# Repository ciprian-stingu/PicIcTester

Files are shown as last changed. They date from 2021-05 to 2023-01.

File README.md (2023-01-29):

# PicIcTester
IC Tester using PICs

I made this project because I have a lot of 7400-series digital logic integrated circuits acquired from flea market and I wanted to verify them.  
The tester is using a **PIC18F452-I/P** to perform the tests and a **PIC16F628A** to handle the display, keypad and relays.

## Main features

* Search IC by name
* Create, run and store and load custom tests directly on tester
* Run tests created on a connected computer
* IC identification
* Can test logic circuits with pinout count between 2 and 28 pins
* IC in narrow or normal packaging
* Default testing will use relays to activate the IC power pins
* IC identification will use low power, so the tester can't damage the IC
* Keypad operation
* Computer connection
* Single sided PCB, so you can made it at home

## Compiled code
Here are the hex files which contain the compiled code for [PIC18F452-I/P aka Tester](binaries/Tester.production.hex) and [PIC16F628A aka Interface](binaries/Interface.production.hex).

## Database
The tester uses a modified database which I found on [Smart-IC-Tester](https://github.com/akshaybaweja/Smart-IC-Tester).  
In order to speed up the search on database I created an index at the start of it. I shrinked it by using the Unix line endings and by merging identical tests. Also some teste were fixed or updated.  
The program which handle the database indexing is in [DbCreate](DbCreate) folder.  
The ready for use database file is [here](Database/database.txt.bin)

## Database storage
To store the database I used an **24LC256** (256Kb I2C compatible 2-wire Serial EEPROM) but you can use an eeprom up to 64KiB in size.

## Display
I'm using a **Nokia 3510i LCD** with a modified code from [Interfacing Nokia 3510i and 5110 LCD with PIC Microcontroller](http://www.toughdev.com/content/2011/03/interfacing-nokia-3510i-and-5110-lcd-with-pic-microcontroller/)

## Font
I'm using a modified and stripped down version of **TINYTYPE** from [8x8 Pixel ROM Font Editor](https://www.min.at/prinz/o/software/pixelfont/)

## Hardware
All the files which you need in order to create the PCBs are in the [hardware](hardware) folder.

## Case
The files for 3D printing a case are available in [FreeCAD](FreeCAD) folder

## Menu &amp; navigation

Navigate in main menu using *UP* and *DOWN* keys, pressing the *OK* key will activate the selected option  

* Search &amp; Test
    * Enter Search IC screen using the *OK* key
        * When in search box you can enter the device name using the keypad (keys *0* through *9*)
        * To select a device use the *DONW* key
            * At this step you can cancel and return to main screen using the *LEFT* key
            * Enter the test screen using the *OK* key
                * Navigate between buttons using *UP* and *DOWN* keys
                * Start testing by selecting *START* button and then press *OK* key
                    * Test result is displayed
                        * Pressing any key will close this screen and return to test screen
                * Return to main menu using *CLOSE* button
* PC Test
    * Enter PC Test screen using the *OK* key
        * To cancel the PC test press any key
        * After receiving the test data from PC, the tester will enter the PC test screen
            * Here you have 3 options: *START*, *SAVE*, *CLOSE*
            * Choosing *START* will run the test received from PC
            * You can save the test in *PIC18F452* EEPROM for later use using the *SAVE* button
            * Return to main menu using *CLOSE* button
* Custom Test
    * Enter Custom test screen using the *OK* key
        * If a previous test was saved, here you have the option to load it back from eeprom
            * Choosing *NO* will proceed to create a new custom test
            * Choosing *YES* will load the test from eeprom and will advance to test screen
        * If no previous test exist or you choose to ignore the existing custom test, it will display the Custom test name screen
            * Enter a test name using the keys *0* through *9*
            * You can remove the last character entered using the *LEFT* key
            * When ready, use the *DOWN* key to select the *OK* button and using the *OK* key advance to Test Pins screen
                * Here you can specify the number of pins for the subject IC, only even numbers and up to 28 pins
                * You can remove the last char using *LEFT* key
                * When ready, use the *DOWN* key to select the *OK* button and using the *OK* key advance to Test cases screen
                    * Here you can specify one test case at a time
                    * You can enter the test case using the keys from *0* through *7*
                        * 0 key -> displays 0 -> INPUT PIN LOW
                        * 1 key -> displays 1 -> INPUT PIN HIGH
                        * 2 key -> displays L -> OUTPUT PIN LOW
                        * 3 key -> displays H -> OUTPUT PIN HIGH
                        * 4 key -> displays G -> PIN as POWER GROUND
                        * 5 key -> displays V -> PIN as POWER VCC
                        * 6 key -> displays X -> DON'T USE the PIN
                        * 7 key -> displays C -> USE the PIN as CLOCK
                    * You can remove the last char using *LEFT* key
                    * You need to enter the same number of chars as the previously specified IC pins. If you have more chars than the number of pins, the tester will ignore excess data.
                    * When ready, use the *DOWN* key to select the *NEXT* button to confirm the current test case
                    * After entering and confirming at least one test case you can use the *DONE* button to advance to Start Test screen
                        * Here you have the same options as on PC Test screen
* Identify IC
    * Enter Identify IC screen using the *OK* key
        * Here you need to specify the number of pins which IC has, using keys *0* through *9*
        * You can remove the last char using *LEFT* key
        * You can return to main menu using *DOWN* key, selecting the *CLOSE* button and using the *OK* key
        * When ready use the *DOWN* key, select *START* button and pressing the *OK* key to start the identifying process
            * The identification process is not using the relays, so in some cases the IC will be not found because, probably, it require more power than the 20mA available from PIC I/O ports
            * Also, if the IC is defective, the identification process will fail
            * When identification process is finished, the result found or not found is displayed. 
                * From this screen, pressing any key will return to main menu
* About
    * Enter About screen using the *OK* key
        * Information about tester will be displayed
        * Pressing any key will return to main menu

## PC communication protocol
The PC can be connected to the tester using an commonly available **USB to UART converter** with a baud rate of 115200/8-N-1 and using unix line endings
The tester will not respond if the line sent was processed correctly, but will send back errors if the data was not ok.
The following protocol is used in order to transmit a test case, one line at a time

```
TEST BEGIN
TEST NAME The Test Name (up to 14 chars)
TEST PINS Number of pins (up to 28 pins and even number)
TEST CASE The test case data (following chars are allowed: 0,1,L,H,G,V,X,C and has to match the number of IC pins)
... more test cases... up to 48 test cases
TEST END

```
You can abort the test transmision using `ABORT`  
After receiving the `END` keyword the tester will respond `Test data complete` and will be ready to run the test

Example
```
TEST BEGIN
TEST NAME 74244
TEST PINS 20
TEST CASE 10H0H0H0HG0H0H0H0H1V
TEST CASE 11H1H1H1HG1H1H1H1H1V
TEST CASE 00L0L0L0LG0L0L0L0L0V
TEST CASE 01H1H1H1HG1H1H1H1H0V
TEST CASE 00H0H0H0HG1L1L1L1L0V
TEST CASE 01L1L1L1LG0H0H0H0H0V
TEST CASE 01H0H1H0HG1L0H1L0H1V
TEST CASE 10H1L0H1LG0H1H0H1H0V
TEST END
```

## Limitations in current implementation
* Only one test case can be saved in tester eeprom memory
* Only 240 bytes of eeprom data is available for storage of a test case
* The database can be up to 64KiB in size
* The communication between PIC18F452-I/P and PIC16F628A is visible on UART
* You can have only 32767 tests in database
* You can have only 48 test cases in each test
* Maximum message length on UART is 79 characters
* 7 relays are used to implement common power configuration for ICs

## Supported ICs
4000, 4001, 4002, 4009, 4049, 4010, 4050, 4011, 4012, 4013, 4015, 4016, 4066, 4017, 4018, 4019, 4020, 4022, 4023, 4024, 4025, 4027, 4028, 4029, 4030, 4031, 4040, 4041, 4042, 4043, 4044, 4048, 4049, 4051, 4053, 4066, 4068, 4069, 40106, 4070, 4071, 4072, 4073, 4075, 4076, 4077, 4078, 4081, 4082, 4093, 4094, 4098, 40106, 40160, 40162, 40161, 40163, 40174, 40175, 40192, 40193, 4501, 4503, 4506, 4510, 4511, 4512, 4518, 4519, 4520, 4529, 4532, 4543, 4572, 7400, 7403, 7437, 7438, 7401, 7402, 7428, 7404, 7405, 7406, 7414, 7416, 7407, 7417, 7408, 7409, 7410, 7412, 7411, 7413, 7418, 7420, 7440, 74140, 7415, 7421, 7422, 7425, 7426, 7427, 7430, 7432, 7442, 7446, 7447, 7450, 7451, 7452, 7455, 7458, 7460, 7461, 7462, 7465, 7472, 7474, 7475, 7485, 7486, 74107, 74109, 74112, 74113, 74123, 74125, 74126, 74132, 74133, 74136, 74137, 74138, 74139, 74145, 74147, 74148, 74151, 74153, 74157, 74158, 74160, 74161, 74162, 74163, 74164, 74165, 74166, 74173, 74174, 74175, 74182, 74190, 74191, 74192, 74193, 74194, 74195, 74237, 74242, 74243, 74244, 74251, 74253, 74257, 74258, 74259, 74260, 74266, 74280, 74283, 74292, 74293, 74294, 74298, 74365, 74366, 74367, 74368, 74373, 74374, 74375, 74386, 74390, 74393, 74589, 74595, 74597

## Assembled tester
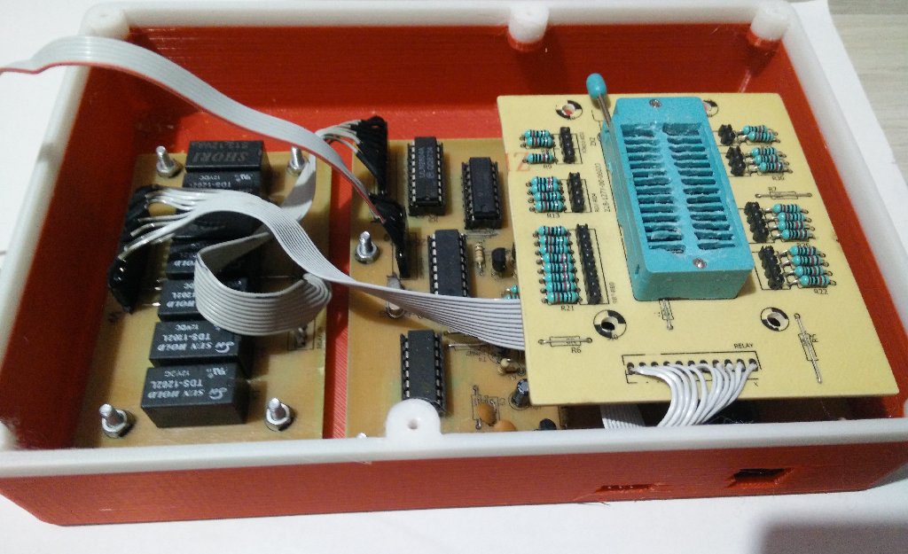
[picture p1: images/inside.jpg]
Inside
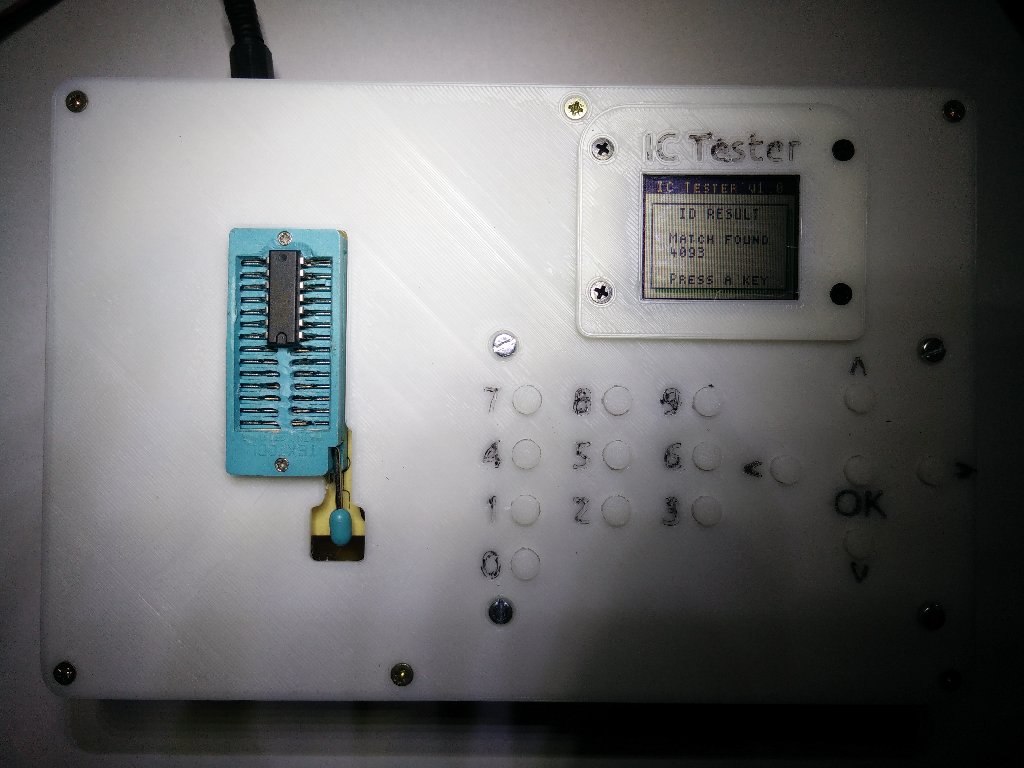
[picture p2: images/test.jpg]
Test
 

## Menu images
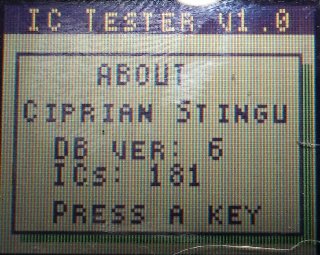
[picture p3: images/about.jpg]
About
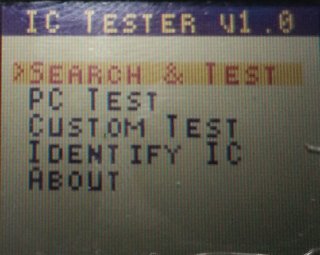
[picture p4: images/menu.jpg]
Menu
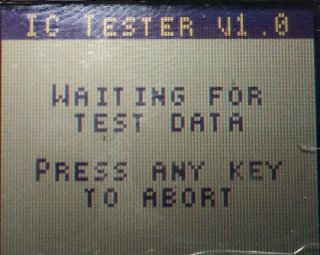
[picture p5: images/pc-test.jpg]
Pc test
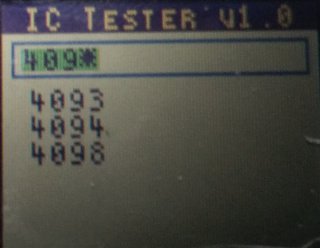
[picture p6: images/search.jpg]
Search
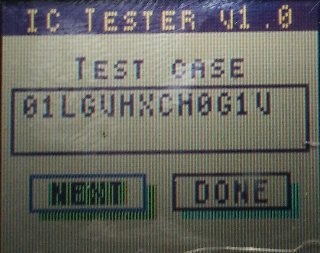
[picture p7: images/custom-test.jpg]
Custom test
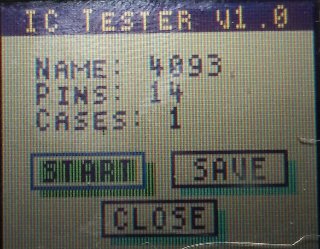
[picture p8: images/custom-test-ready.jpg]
Custom test ready
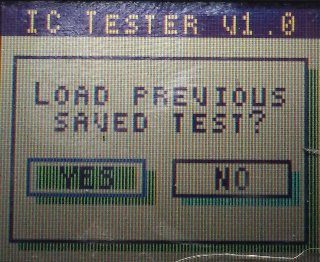
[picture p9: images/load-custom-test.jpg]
Load custom test
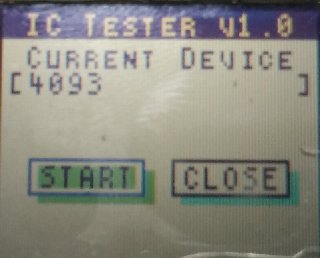
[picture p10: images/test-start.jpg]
Test start
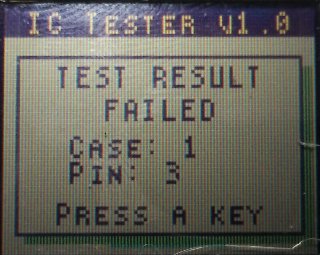
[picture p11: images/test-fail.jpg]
Test fail
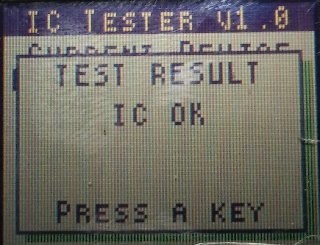
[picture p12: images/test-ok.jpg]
Test ok


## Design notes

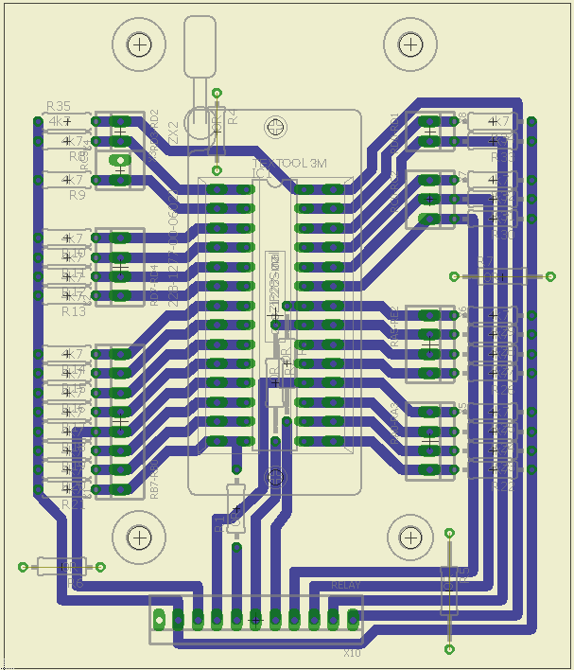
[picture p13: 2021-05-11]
hardware/socket-pcb.png

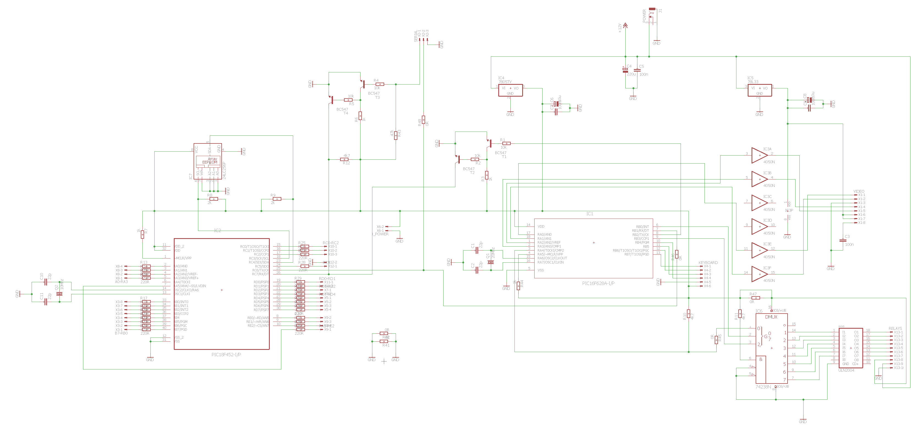
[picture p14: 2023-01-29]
hardware/main-schematic.png

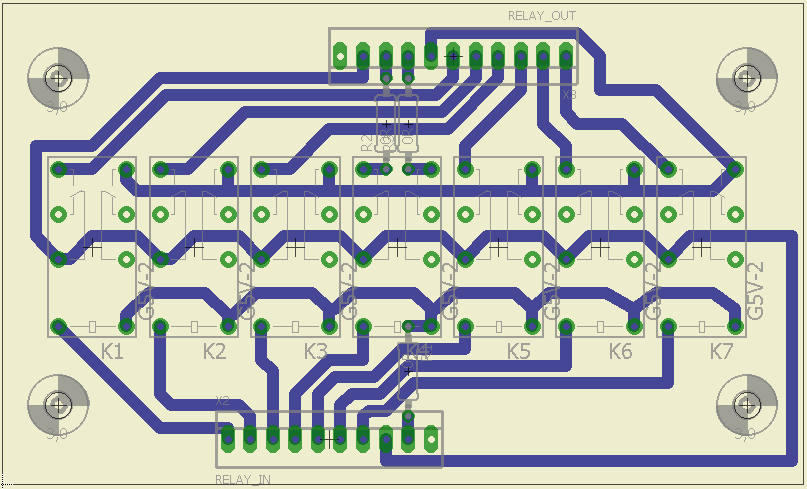
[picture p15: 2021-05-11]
hardware/relay-pcb.png

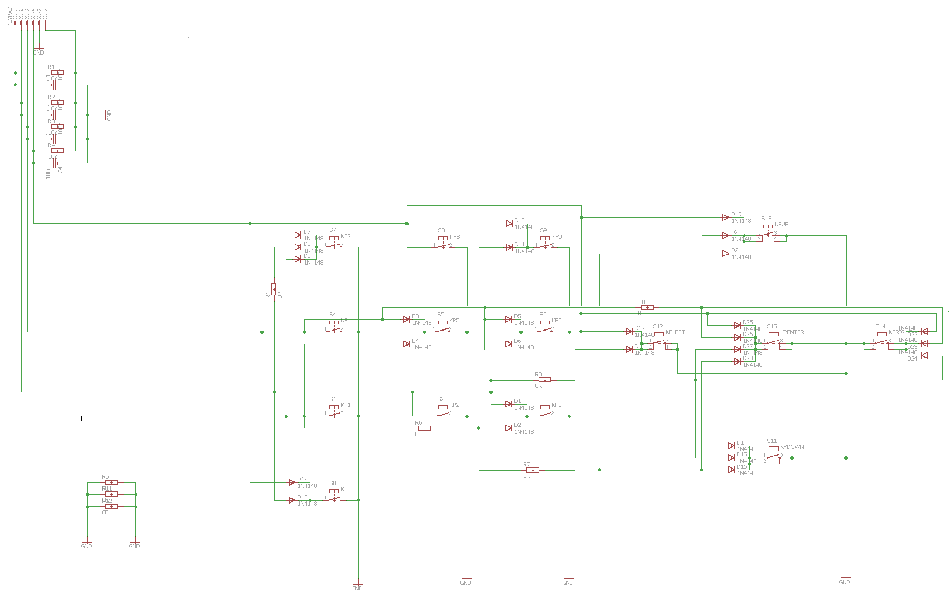
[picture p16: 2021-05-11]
hardware/keypad-schematic.png

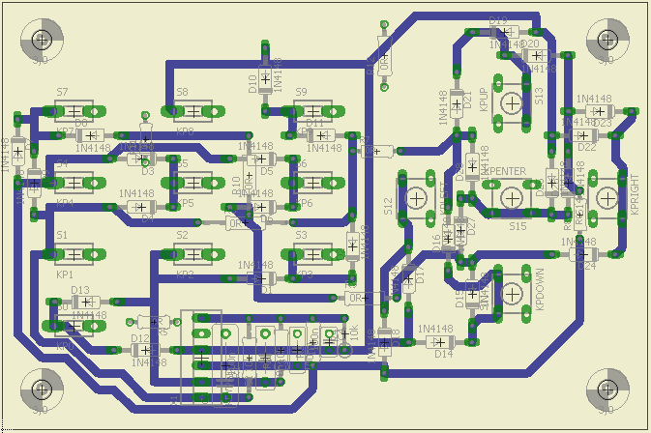
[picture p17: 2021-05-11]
hardware/keypad-pcb.png

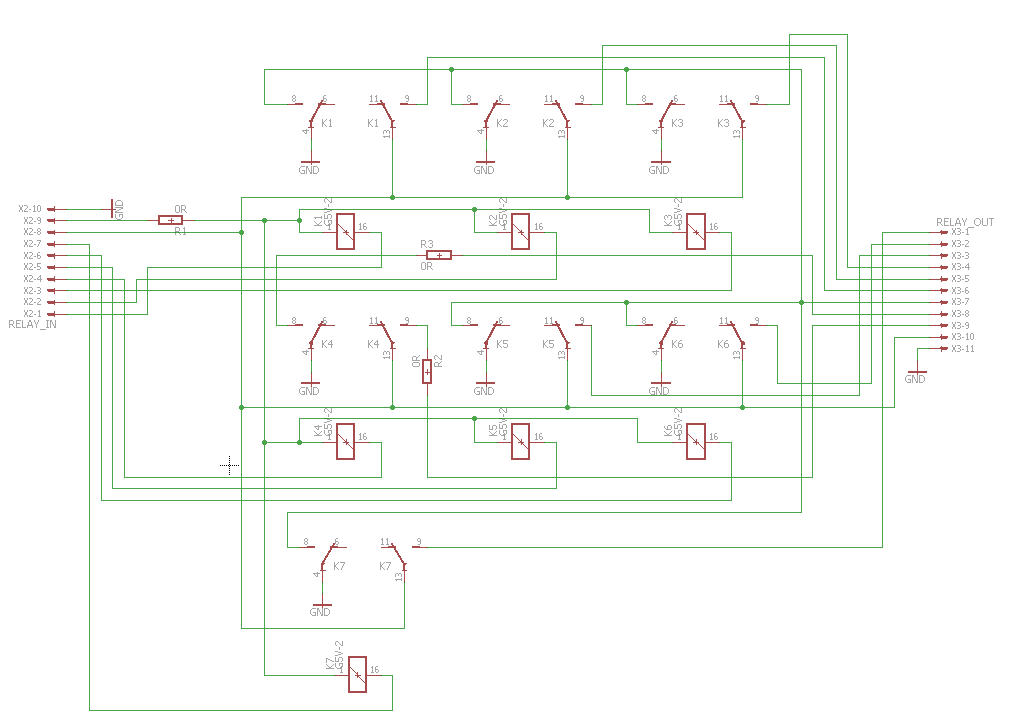
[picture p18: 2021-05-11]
hardware/relay-schematic.png

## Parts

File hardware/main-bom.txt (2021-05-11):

Part Value          Description                               
C1   22p                      
C2   22p                          
C3   100n                          
C4   220u                 
C5   100n                           
C6   10u                  
C7   100n                           
C8   10u                  
C9   100n                           
C10  22p                            
C11  22p                              
IC1  PIC16F628A-I/P 8 Bit CMOS Microcontrollers               
IC2  PIC18F452-I/P  Flash Microcontrollers                    
IC3  4050N          Hex non-inverting BUFFER                  
IC4  7805TV         Positive VOLTAGE REGULATOR                
IC5  78L33          Positive VOLTAGE REGULATOR                
IC6  74238N         1 of 8 noninverting DECODER/DEMULTIPLEXER 
IC7  24LC256P       Serial EEPROM                             
IC8  ULN2004        DRIVER ARRAY                              
J1   POWER          DC POWER JACK                             
Q1   20Mhz          CRYSTAL                                   
Q2   10Mhz          CRYSTAL                                   
R1   10k                             
R2   10k                             
R3   1k                              
R4   10k                             
R5   10k                             
R6   1k                              
R7   1k                              
R8   2k                             
R9   2k                              
R10  4k7                             
R11  4k7                          
R12  4k7                             
R13  220R                            
R14  220R                            
R15  220R                            
R16  220R                            
R17  220R                            
R18  220R                            
R19  220R                            
R20  220R                            
R21  220R                            
R22  220R                            
R23  220R                            
R24  220R                            
R25  220R                            
R26  220R                            
R27  220R                            
R28  220R                            
R29  220R                            
R30  220R                            
R31  220R                            
R32  220R                            
R33  220R                            
R34  220R                            
R35  220R                            
R36  220R                            
R37  220R                            
R38  220R                            
R39  220R                            
R40  220R                            
R41  0R                              
R42  0R                              
R43  47k                             
R44  1k                              
R45  0R                              
R46  0R                              
R47  0R                              
R48  0R                              
T1   BC547          NPN TRANSISTOR                            
T2   BC547          NPN TRANSISTOR                            
T3   BC547          NPN TRANSISTOR                            
T4   BC547          NPN TRANSISTOR                            
X1   VIDEO          .100" (2.54mm) Center Header - 8 Pin      
X2   SERIAL         .100" (2.54mm) Center Header - 3 Pin      
X3   RB7-RB0        .100" (2.54mm) Center Header - 8 Pin      
X4   KEYBOARD       .100" (2.54mm) Center Header - 6 Pin      
X5   RD7-RD4        .100" (2.54mm) Center Header - 4 Pin      
X6   LED_POWER      .100" (2.54mm) Center Header - 2 Pin      
X7   RD3-RD2        .100" (2.54mm) Center Header - 2 Pin      
X8   RA0-RA3        .100" (2.54mm) Center Header - 4 Pin      
X9   RA5-RE2        .100" (2.54mm) Center Header - 4 Pin      
X10  RC0-RC2        .100" (2.54mm) Center Header - 3 Pin      
X11  RD0-RD1        .100" (2.54mm) Center Header - 2 Pin      
X12  RC5            .100" (2.54mm) Center Header - 2 Pin      
X13  RELAYS         .100" (2.54mm) Center Header - 10 Pin

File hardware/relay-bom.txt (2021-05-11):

Part Value         Description                            
K1                 5-12V Relay                        
K2                 5-12V Relay                        
K3                 5-12V Relay                        
K4                 5-12V Relay                        
K5                 5-12V Relay                        
K6                 5-12V Relay                        
K7                 5-12V Relay                        
R1   0R                          
R2   0R                          
R3   0R                         
X2   RELAY_IN      .100" (2.54mm) Center Header - 10 Pin  
X3   RELAY_OUT     .100" (2.54mm) Center Header - 11 Pin

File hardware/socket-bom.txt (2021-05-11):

Part Value             Description                             
IC1  ZIF28             Narrow ZIF                           
R1   0R                               
R2   0R                               
R3   0R                               
R4   0R                               
R5   0R                               
R6   0R                               
R7   0R                               
R8   4k7                              
R9   4k7                              
R10  4k7                              
R11  4k7                              
R12  4k7                              
R13  4k7                              
R14  4k7                              
R15  4k7                              
R16  4k7                              
R17  4k7                              
R18  4k7                              
R19  4k7                              
R20  4k7                              
R21  4k7                              
R22  4k7                              
R23  4k7                              
R24  4k7                              
R25  4k7                              
R26  4k7                              
R27  4k7                              
R28  4k7                              
R29  4k7                              
R30  4k7                              
R31  4k7                              
R32  4k7                              
R33  4k7                              
R34  4k7                              
R35  4k7                              
X1   RB7-RB0           .100" (2.54mm) Center Header - 8 Pin   
X2   RD7-RD4           .100" (2.54mm) Center Header - 4 Pin   
X3   RC5               .100" (2.54mm) Center Header - 2 Pin   
X4   RD3-RD2           .100" (2.54mm) Center Header - 2 Pin   
X5   RA0-RA3           .100" (2.54mm) Center Header - 4 Pin   
X6   RA5-RE2           .100" (2.54mm) Center Header - 4 Pin   
X7   RC0-RC2           .100" (2.54mm) Center Header - 3 Pin   
X8   RD0-RD1           .100" (2.54mm) Center Header - 2 Pin   
X10  RELAY             .100" (2.54mm) Center Header - 11 Pin  
ZX2  ZIF28				Normal ZIF

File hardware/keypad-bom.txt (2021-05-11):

Part Value         Description                            
C1   100n                       
C2   100n                       
C3   100n                      
C4   100n                       
D1   1N4148                                          
D2   1N4148                                          
D3   1N4148                                          
D4   1N4148                                          
D5   1N4148                                          
D6   1N4148                                          
D7   1N4148                                          
D8   1N4148                                          
D9   1N4148                                          
D10  1N4148                                          
D11  1N4148                                          
D12  1N4148                                          
D13  1N4148                                          
D14  1N4148                                          
D15  1N4148                                          
D16  1N4148                                          
D17  1N4148                                          
D18  1N4148                                          
D19  1N4148                                          
D20  1N4148                                          
D21  1N4148                                          
D22  1N4148                                          
D23  1N4148                                          
D24  1N4148                                          
D25  1N4148                                          
D26  1N4148                                          
D27  1N4148                                          
D28  1N4148                                           
R1   10k                         
R2   10k                         
R3   10k                         
R4   10k                        
R5   0R                          
R6   0R                          
R7   0R                          
R8   R0                          
R9   0R                          
R10  0R                          
R11  0R                          
R12  0R                          
S0   KP0           DTS-3                                            
S1   KP1           DTS-3                                                    
S2   KP2           DTS-3                                                      
S3   KP3           DTS-3                                                        
S4   KP4           DTS-3                                                       
S5   KP5           DTS-3                                                      
S6   KP6           DTS-3                                                     
S7   KP7           DTS-3                                                       
S8   KP8           DTS-3                                                       
S9   KP9           DTS-3                                                        
S11  KPDOWN        DTS-6                                                       
S12  KPLEFT        DTS-6                                                       
S13  KPUP          DTS-6                                                         
S14  KPRIGHT       DTS-6                                                         
S15  KPENTER       DTS-6                                                        
X1   KEYPAD        .100" (2.54mm) Center Header - 6 Pin

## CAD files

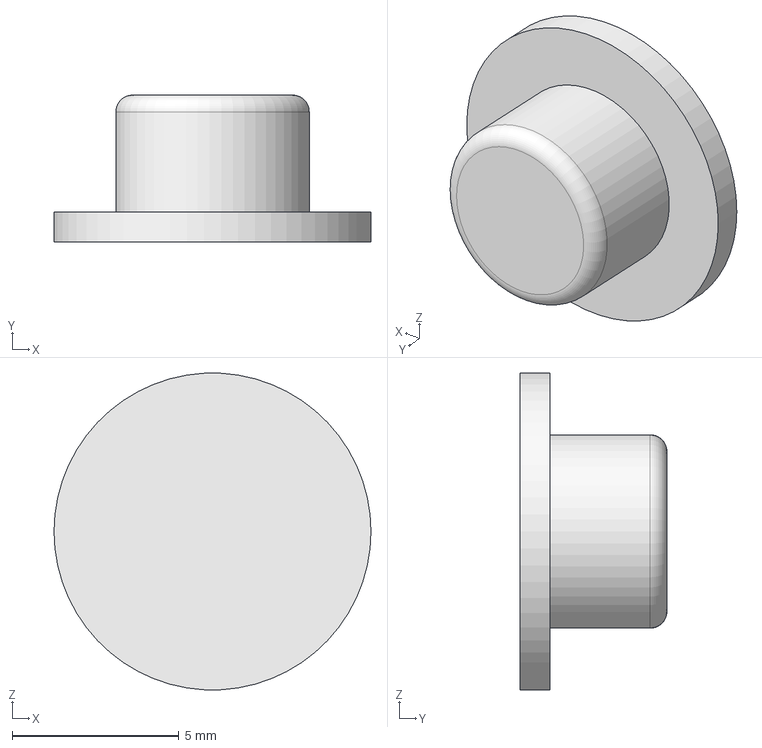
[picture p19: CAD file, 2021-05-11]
FreeCAD/button.FCStd
9.50 x 4.40 x 9.49 mm

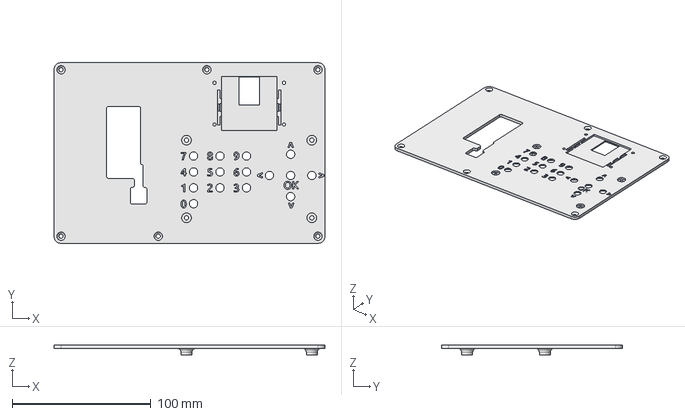
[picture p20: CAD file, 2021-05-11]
FreeCAD/face-plate.FCStd
195.0 x 130.0 x 7.50 mm

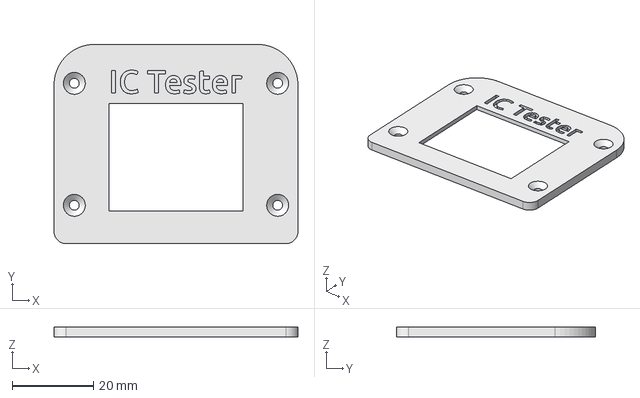
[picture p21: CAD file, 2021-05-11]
FreeCAD/screen-plate.FCStd
60.0 x 49.0 x 2.50 mm

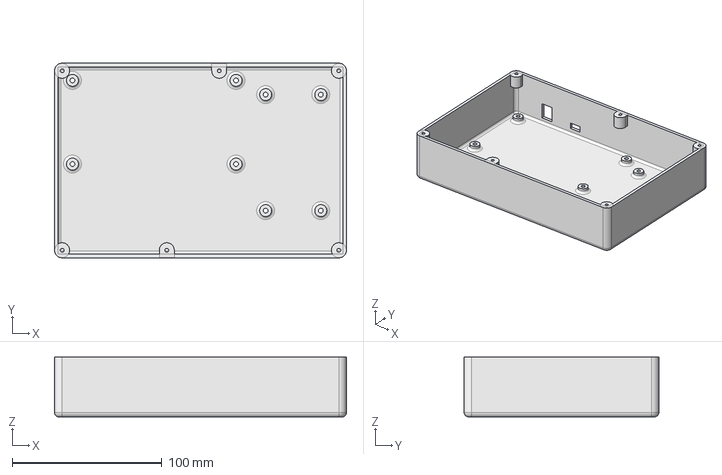
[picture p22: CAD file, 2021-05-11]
FreeCAD/case.FCStd
195.0 x 130.0 x 40.0 mm

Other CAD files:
FreeCAD/button.stl
FreeCAD/case.stl
FreeCAD/face-plate.stl
FreeCAD/screen-plate.stl

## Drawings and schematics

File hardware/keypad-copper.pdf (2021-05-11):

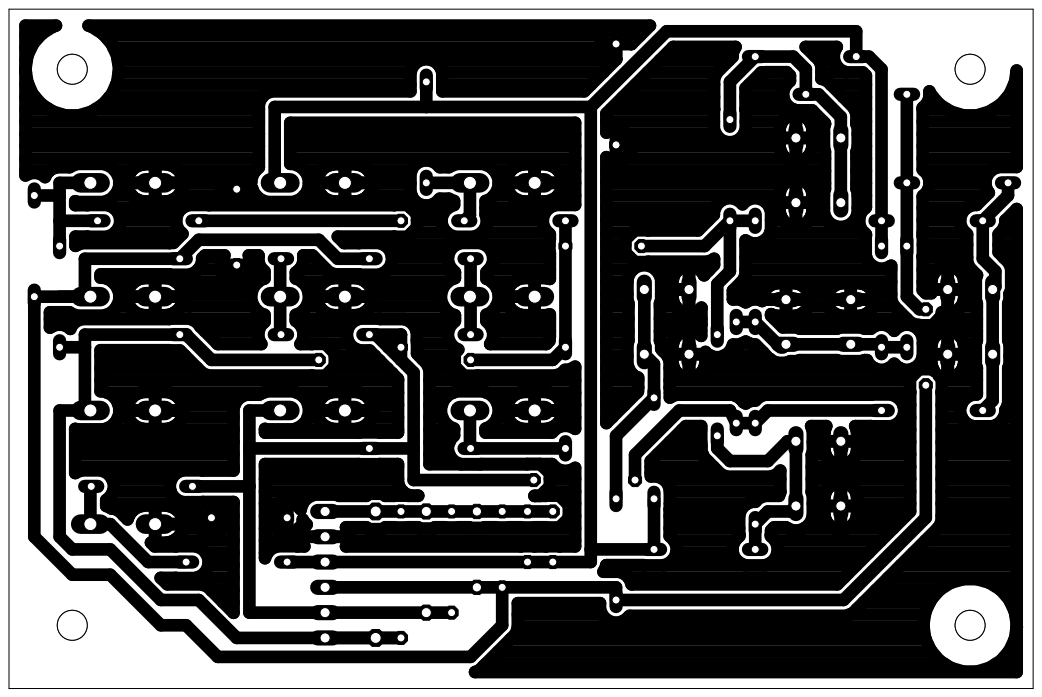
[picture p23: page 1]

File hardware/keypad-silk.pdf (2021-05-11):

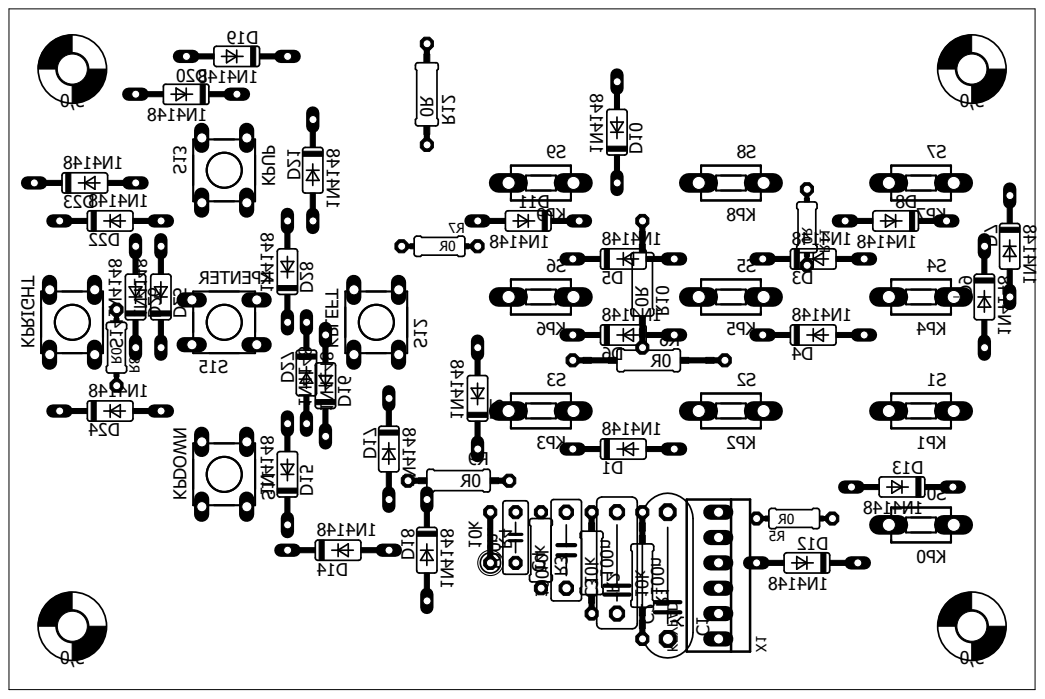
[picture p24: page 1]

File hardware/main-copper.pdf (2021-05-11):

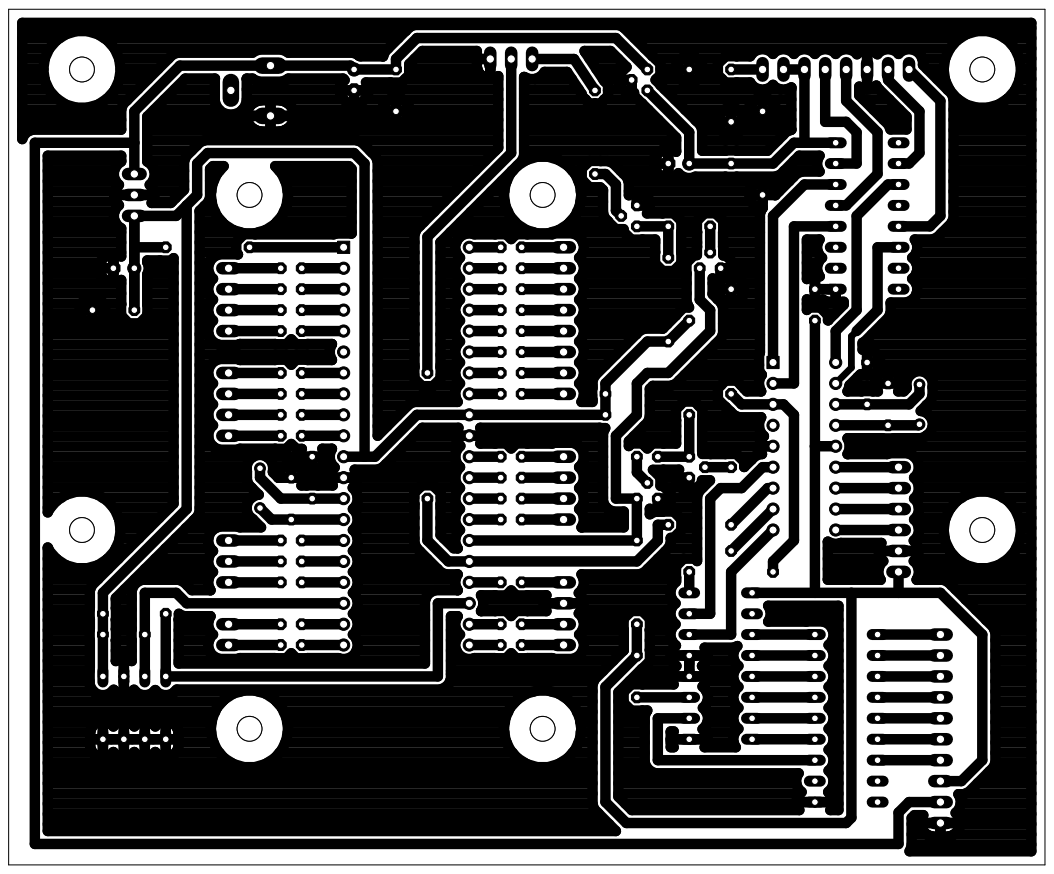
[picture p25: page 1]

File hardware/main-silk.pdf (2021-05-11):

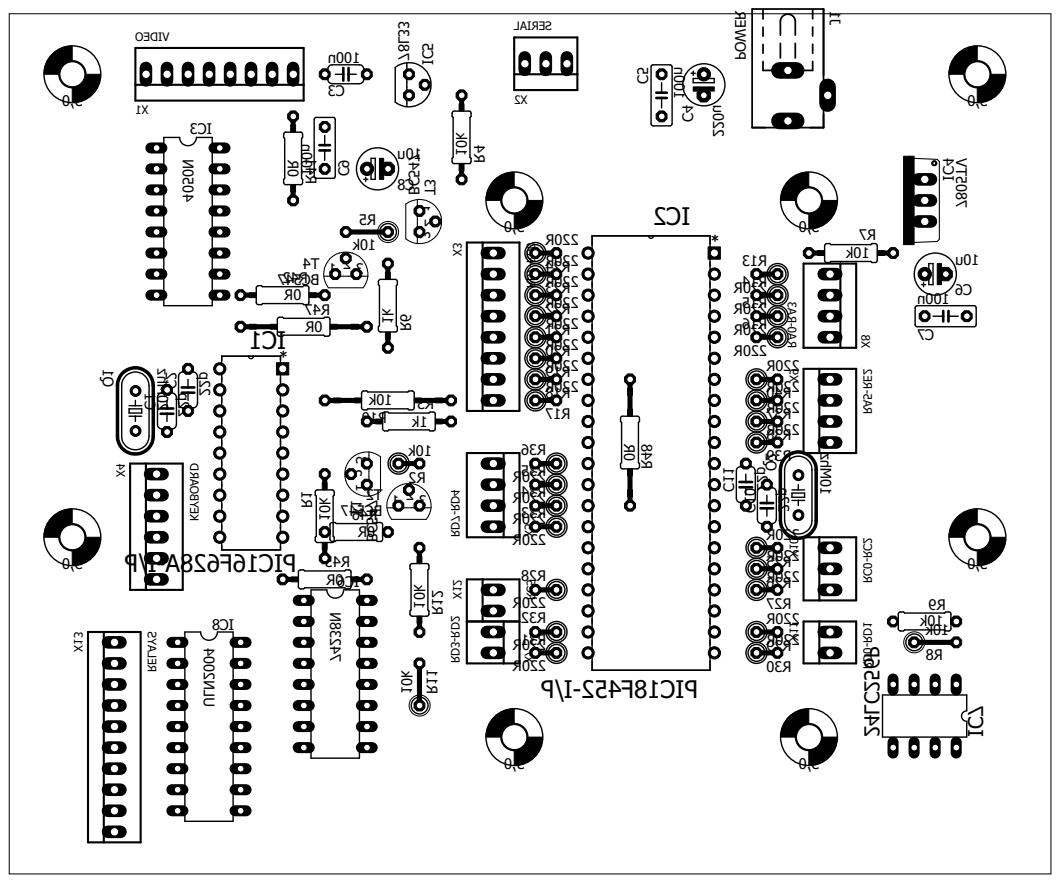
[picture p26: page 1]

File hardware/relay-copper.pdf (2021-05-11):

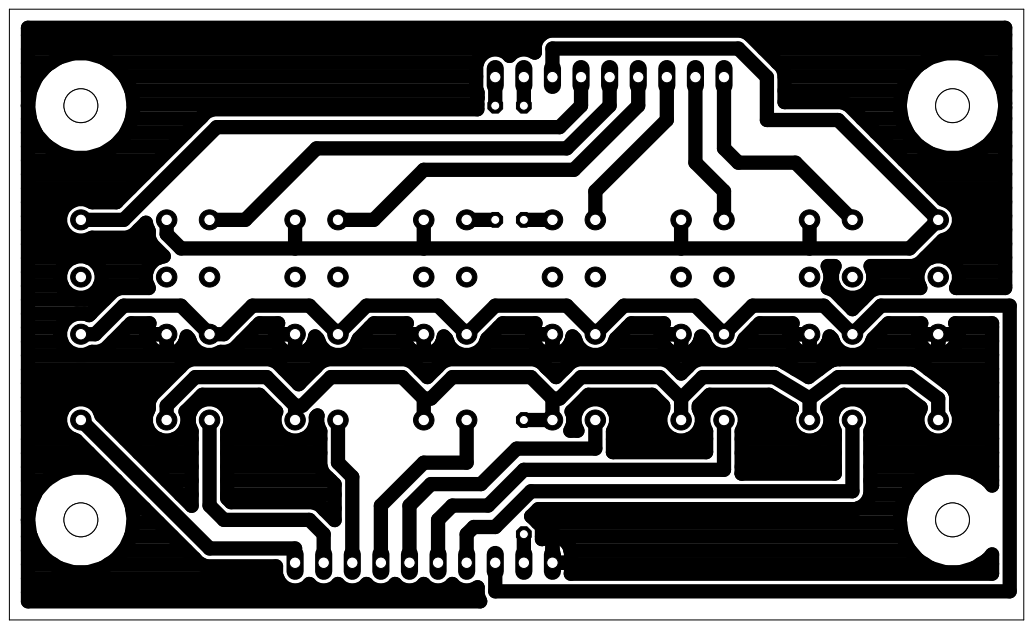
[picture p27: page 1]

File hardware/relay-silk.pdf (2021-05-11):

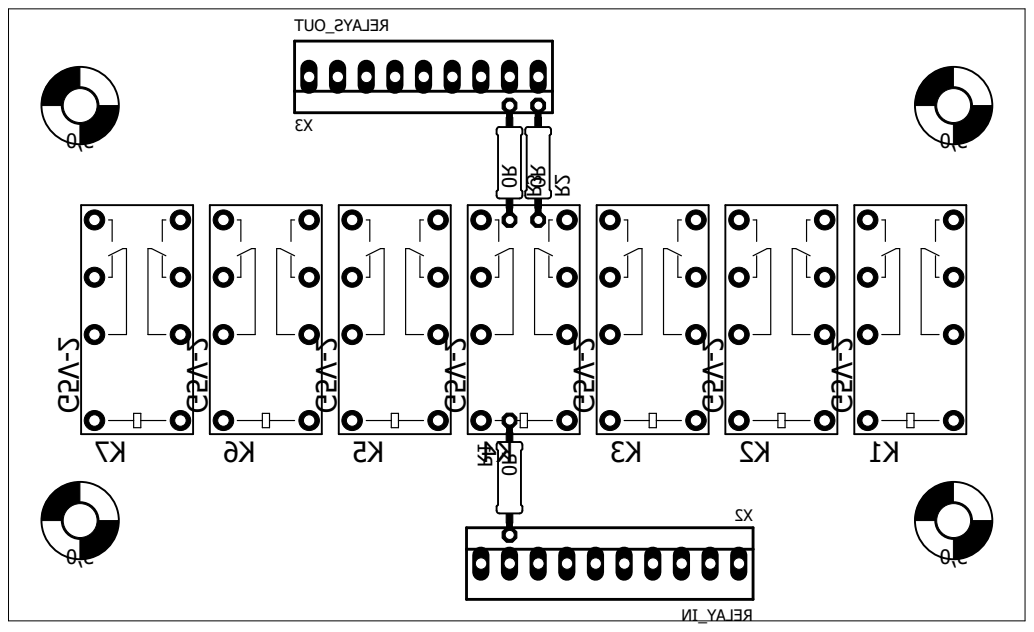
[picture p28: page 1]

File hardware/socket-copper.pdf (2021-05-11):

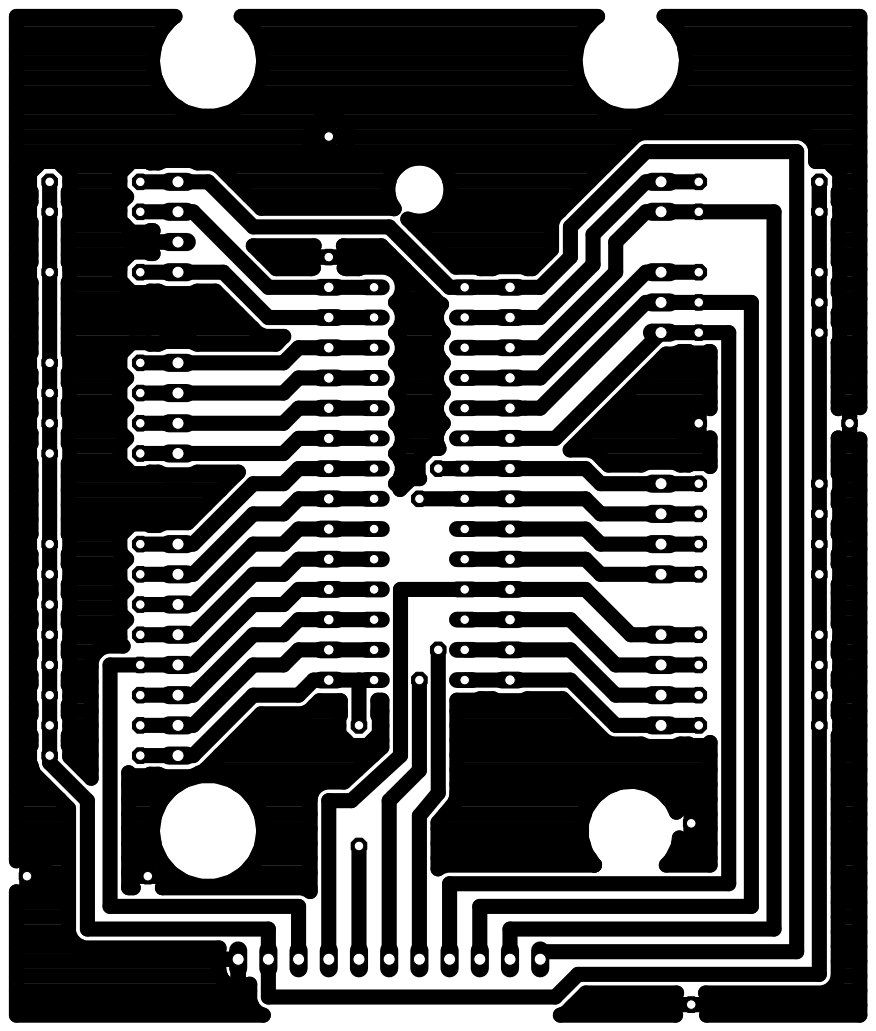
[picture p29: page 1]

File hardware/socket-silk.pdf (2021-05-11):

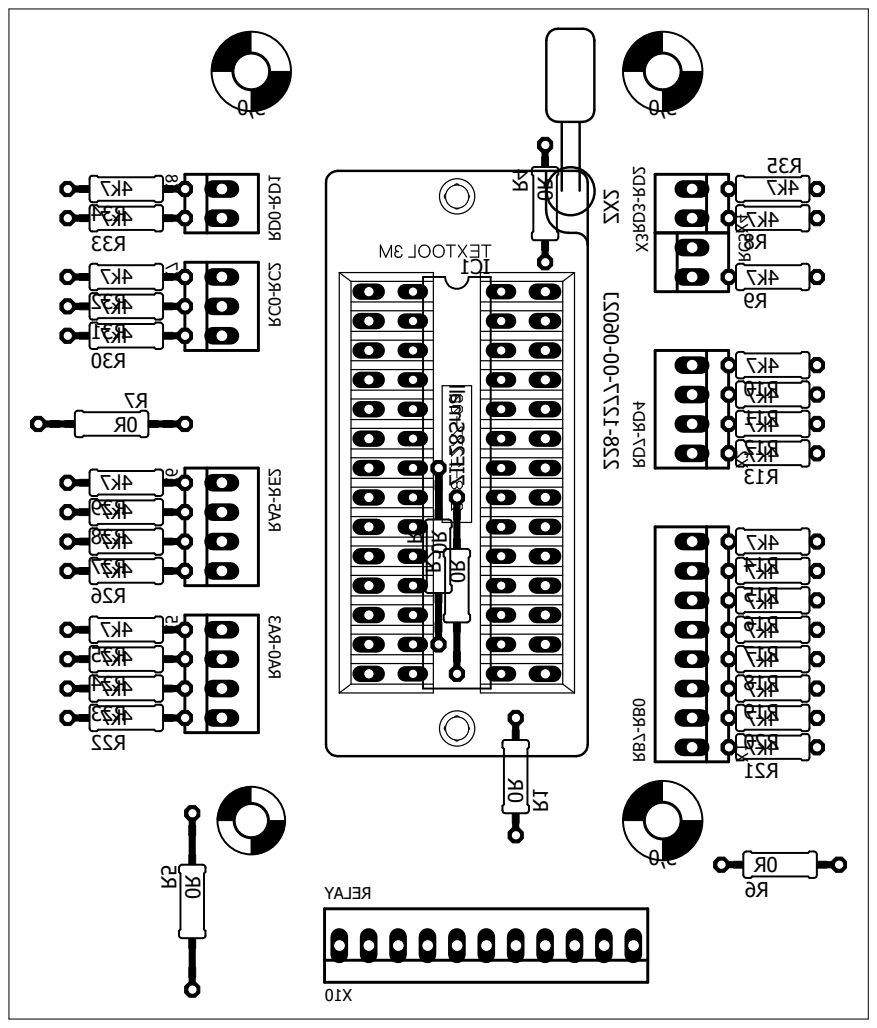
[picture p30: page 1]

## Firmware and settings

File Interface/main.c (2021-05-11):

/**
 * 
 * PicIcTester Interface
 * 
 * Copyright (C) 2020-2021 Ciprian Stingu
 * ciprian dot stingu at gmail dot com
 * 
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
 * File:   main.c
 * Author: Ciprian Stingu
 *
 * Created on July 7, 2020, 7:11 PM
 */


#include "main.h"

void main(void) 
{
    // Enable all unmasked global INT
    GIE = 1;
    // Enable Peripheral interrupt
    PEIE = 1;
    // disable comparators
    CM0 = 1;
    CM1 = 1;
    CM2 = 1;
    
    RelaysInit();
    KeypadInit();
    UartInit();
    LcdInit();
    Timer0Init();
    
    ShowBootingMessage();
    
    //memset call will make code bigger...
    for(uint8_t i = 0; i <= UART_MESSAGE_MAX_LENGTH; i++) {
        UartMessage[i] = 0x00;
    }
    UartMessageLength = 0;
    
    __delay_ms(2000);
    UartWriteString("_I OK\n"); //ready to accept messages
    
    ResetKeypadData();
    
    while(1)
    {
        if(UartMessageLength == UART_MESSAGE_MAX_LENGTH)
        {
            ProcessCommand();
            
            for(uint8_t i = 0; i <= UART_MESSAGE_MAX_LENGTH; i++) {
                UartMessage[i] = 0x00;
            }
            UartMessageLength = 0;
        }
        else if(KeypadData != KEY_NONE) //send key as long as no command is executed
        {
            // send key data
            // "_K key"
            char keyCommand[6] = {'_', 'K', ' ', KeypadData, '\n'};
            UartWriteString(keyCommand);
            KeypadData = KEY_NONE;
        }
    }
}

void ProcessCommand(void)
{
    if(UartMessage[0] != '_') {
        return;
    }
    
    // relay command
    // "_R no"
    // no - 1/2/3/4/5/6/7 in hex format
    if(UartMessage[1] == 'R' && UartMessage[2] == ' ') 
    {
        uint8_t relayNo = AsciiHexToByte(&UartMessage[3]);
        
        EnableRelay(relayNo);
        UartWriteString("_R OK\n");
    }
    // clear screen
    // "_C xxyywwhhbb"
    // all numbers in ascii hex format
    // xx - x origin, yy - y origin
    // ww - image width, hh - image height
    // bb - background color
    else if(UartMessage[1] == 'C' && UartMessage[2] == ' ')
    {
        uint8_t x = AsciiHexToByte(&UartMessage[3]);
        uint8_t y = AsciiHexToByte(&UartMessage[5]);
        uint8_t width = AsciiHexToByte(&UartMessage[7]);
        uint8_t height = AsciiHexToByte(&UartMessage[9]);
        uint8_t bgColor = AsciiHexToByte(&UartMessage[11]);
        
        LcdClear(x, y, width, height, bgColor);
        UartWriteString("_C OK\n");
    }
    // display graphic data
    // "_G xxyywwhhccbb graphic_data_bytes_raw
    // all numbers in ascii hex format
    // xx - x origin, yy - y origin
    // ww - image width, hh - image height
    // cc - foreground color, bb - background color
    // graphic data in ascii hex format
    // max of 31 hex bytes of graphic data
    else if(UartMessage[1] == 'G' && UartMessage[2] == ' ')
    {
        uint8_t x = AsciiHexToByte(&UartMessage[3]);
        uint8_t y = AsciiHexToByte(&UartMessage[5]);
        uint8_t width = AsciiHexToByte(&UartMessage[7]);
        uint8_t height = AsciiHexToByte(&UartMessage[9]);
        uint8_t color = AsciiHexToByte(&UartMessage[11]);
        uint8_t bgColor = AsciiHexToByte(&UartMessage[13]);
        
        LcdDisplayGraphic(x, y, width, height, color, bgColor, &UartMessage[16]);
        UartWriteString("_G OK\n");
    }
    // unknown command
    // so send error 
    else 
    {
        __delay_ms(5);
        UartWriteString("_E\n");
    }
}

void __interrupt() ISR(void)
{
    //new uart data
    if(RCIF)
    {
        if(OERR) // check for overrun error and reset
        {
            CREN = 0; 
            CREN = 1;
        }
        // RCREG contain UART data
        if(RCREG == 0x0A) {
            UartMessageLength = UART_MESSAGE_MAX_LENGTH;
        }
        else if(UartMessageLength < UART_MESSAGE_MAX_LENGTH) {
            UartMessage[UartMessageLength++] = RCREG;
        }
        RCIF = 0;
    }
    
    //new keypad key
    if(RBIF)
    {   
        T0IE = 0; // stop timer0
        
        // compose keypad data from 4 bits 
        uint8_t data = ~(((RB4 & 0x01) << 3) | ((RB5 & 0x01) << 2) | ((RB6 & 0x01) << 1) | (RB7 & 0x01)) & 0x0F;
        //add it to debounced key data
        KeypadDataDebounced |= data;
            
        // reset timer0
        //60 - 10ms
        //21 - 12ms
        TMR0 = 0x3C;
        KeypadDebounceCounter = 0; // reset the delay
        T0IE = 1; // reenable timer0
        
        RBIF = 0;
    }
    
    //debounce keypad data
    if(TMR0IF && T0IE)
    {
        //if no pins active compose the keypad data
        if(RB4 && RB5 && RB6 && RB7 && KeypadDebounceCounter++ >= DEBOUNCER_DELAY && KeypadDataDebounced)
        {
            if(KeypadDataDebounced > 0 && KeypadDataDebounced < 0x0A) {
                KeypadData = KeypadDataDebounced + '0';
            }
            else if(KeypadDataDebounced == 0x0A) {
                KeypadData = '0';
            }
            else {
                KeypadData = (KeypadDataDebounced - 11) + 'A';
            }
            
            T0IE = 0; // stop timer0
            KeypadDataDebounced = KEY_NONE;
            KeypadDebounceCounter = 0;
        }
        
        TMR0IF = 0;
    }
}

uint8_t AsciiHexToByte(char *value)
{
    uint8_t result = (*value <= '9' ? *value - '0' : *value - 'A' + 10) << 4;
    value++;
    result |= (*value <= '9' ? *value - '0' : *value - 'A' + 10);
    
    return result;
}

void ShowBootingMessage(void)
{
    LcdDisplayGraphic(16, 26, 66, 1, 3, 255, "FFFFFFFFFFFFFFFFFF");
    LcdDisplayGraphic(16, 26, 1, 14, 3, 255, "8080808080808080808080808080");
    LcdDisplayGraphic(16, 39, 66, 1, 3, 255, "FFFFFFFFFFFFFFFFFF");
    LcdDisplayGraphic(81, 26, 1, 14, 3, 255, "8080808080808080808080808080");
    LcdDisplayGraphic(19, 40, 66, 1, 28, 255, "FFFFFFFFFFFFFFFFFF");
    LcdDisplayGraphic(19, 41, 66, 1, 28, 255, "FFFFFFFFFFFFFFFFFF");
    LcdDisplayGraphic(82, 29, 1, 13, 28, 255, "80808080808080808080808080");
    LcdDisplayGraphic(83, 29, 1, 13, 28, 255, "80808080808080808080808080");
    LcdDisplayGraphic(84, 29, 1, 13, 28, 255, "80808080808080808080808080");
    LcdDisplayGraphic(19, 30, 30, 6, 0, 255, "7000000048C31C3871248810492488104924881070C30838");
    LcdDisplayGraphic(49, 30, 30, 6, 0, 255, "0000000048E0000069000000796000005920000048C10410");
}

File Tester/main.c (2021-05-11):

/**
 * 
 * PicIcTester Tester
 * 
 * Copyright (C) 2020-2021 Ciprian Stingu
 * ciprian dot stingu at gmail dot com
 * 
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
 * File:   main.c
 * Author: Ciprian Stingu
 *
 * Created on July 17, 2020, 2:00 PM
 */


#include "main.h"

void main(void) 
{
    // Enable all unmasked global INT
    GIE = 1;
    // Enable Peripheral interrupt
    PEIE = 1;
    //disable comparators
    CCP1M0 = 0;
    CCP1M1 = 0;
    CCP1M2 = 0;
    CCP1M3 = 0;
    CCP2M0 = 0;
    CCP2M1 = 0;
    CCP2M2 = 0;
    CCP2M3 = 0;
    // A/D Port Configuration Control bits
    // 011x - Digital I/O
    PCFG3 = 0;
    PCFG2 = 1;
    PCFG1 = 1;
    PCFG0 = 0;
    // shut-off A/D converter
    ADON = 0;
    // General purpose I/O mode
    PSPMODE = 0;
    
    I2cInit();
    UartInit();
    
    ClearString(UartMessage, UART_MESSAGE_MAX_LENGTH + 1);
    UartMessageLength = 0;
    
    ClearString(I2cData, I2C_DATA_MAX_LENGTH + 1);
    I2cDataLength = 0;
    
    ClearString(SelectedDeviceName, SELECTED_DEVICE_NAME_MAX_LENGTH + 1);
    
    __delay_ms(250);
    ReadDatabaseInfo();
    
    //wait for interface to init
    while(InterfaceCmdStatus != INTERFACE_CMD_DONE) {
        __delay_ms(1);
    }
    InitInterfaceScreen();
    KeypadData = KEY_NONE;
    
    ResetHardware(TRUE);
    
    while(TRUE)
    {
        if(UartMessageLength == UART_MESSAGE_MAX_LENGTH)
        {
            ProcessCommand();
            
            ClearString(UartMessage, UART_MESSAGE_MAX_LENGTH + 1);
            UartMessageLength = 0;
        }
        else if(ScreenChanged)
        {
            ScreenChanged = FALSE;
            MenuChanged = FALSE;
            
            if(ActiveScreen == MAIN_SCREEN) {
                DisplayMainScreen();
            }
            else if(ActiveScreen == SEARCH_SCREEN) {
                DisplaySearchScreen();
            }
            else if(ActiveScreen == PC_TEST_SCREEN) {
                DisplayPcTestScreen();
            }
            else if(ActiveScreen == CUSTOM_TEST_SCREEN) {
                DisplayCustomTestScreen();
            }
            else if(ActiveScreen == IDENTIFY_IC_SCREEN) 
            {
                if(IdentifyIcStatus == IDENTIFY_IC_STATUS_RUN) 
                {
                    if(IdentifyIcTestIndex < TestDataRecordsCount) 
                    {
                        uint8_t identifyResult = IdentifyIcTest(IdentifyIcTestIndex++, IdentifyIcPinsCount, IdentifyIcDeviceName);
                        if(identifyResult != INVALID_RESULT) {
                            ActiveScreen = IDENTIFY_IC_RESULT_SCREEN;
                        }
                    }
                    else {
                        ActiveScreen = IDENTIFY_IC_RESULT_SCREEN;
                    }
                    ScreenChanged = TRUE;
                }
                else {
                    DisplayIdentifyIcScreen();
                }
            }
#ifdef HARDWARE_DEBUG
            else if(ActiveScreen == HWDEBUG_SCREEN) {
                DisplayHwDebug();
            }
#else
            else if(ActiveScreen == ABOUT_SCREEN) {
                DisplayAboutScreen();
            }
#endif
            else if(ActiveScreen == SEARCH_IC_INFO_SCREEN) {
                DisplaySearchIcInfoScreen();
            }
            else if(ActiveScreen == TEST_SCREEN) {
                DisplayTestScreen();
            }
            else if(ActiveScreen == TEST_RESULT_SCREEN) {
                DisplayTestResultScreen();
            }
            else if(ActiveScreen == IDENTIFY_IC_RESULT_SCREEN) 
            {
                ResetHardware(FALSE);
                DisplayIdentifyIcResultScreen();
            }
        }
        else if(MenuChanged)
        {
            MenuChanged = FALSE;
            
            if(ActiveScreen == MAIN_SCREEN) {
                UpdateMainMenu();
            }
            else if(ActiveScreen == SEARCH_SCREEN) {
                UpdateSearchMenu();
            }
            else if(ActiveScreen == PC_TEST_SCREEN) {
                UpdatePcTestMenu();
            }
            else if(ActiveScreen == CUSTOM_TEST_SCREEN) 
            {
                if(CustomTestStatus == CUSTOM_TEST_READY) {
                    UpdateCustomTestMenu();
                }
                else if(CustomTestStatus == CUSTOM_TEST_EXISTS) {
                    UpdateCustomTestPreviousMenu();
                }
                else 
                {
                    if(CustomTestStep == CUSTOM_TEST_NAME) {
                        UpdateCustomTestNameStepMenu();
                    }
                    else if(CustomTestStep == CUSTOM_TEST_PINS) {
                        UpdateCustomTestPinsStepMenu();
                    }
                    else if(CustomTestStep == CUSTOM_TEST_CASE) {
                        UpdateCustomTestItemStepMenu();
                    }
                }
            }
            else if(ActiveScreen == IDENTIFY_IC_SCREEN) {
                UpdateIdentifyIcMenu();
            }
#ifdef HARDWARE_DEBUG
            else if(ActiveScreen == HWDEBUG_SCREEN)
            {
                UpdateHwDebugMenu();
            }
#endif
            else if(ActiveScreen == TEST_SCREEN) {
                UpdateTestMenu();
            }
        }
        else if(KeypadData != KEY_NONE)
        {            
            OnKeyUpdateScreen();
            KeypadData = KEY_NONE;
        }
    }
}

void __interrupt() ISR(void)
{
    if(RCIF)
    {
        if(OERR) // check for overrun error and reset
        {
            CREN = 0; 
            CREN = 1;
        }
        // RCREG contain UART data
        if(RCREG == 0x0A) {
            UartMessageLength = UART_MESSAGE_MAX_LENGTH;
        }
        else if(UartMessageLength < UART_MESSAGE_MAX_LENGTH) {
            UartMessage[UartMessageLength++] = RCREG;
        }
        RCIF = 0;
    }
    
    //process interface messages
    if(UartMessageLength == UART_MESSAGE_MAX_LENGTH && UartMessage[0] == '_')
    {
        // all cmds _I/_C/_G/_R OK mesage
        if(UartMessage[2] == ' ' && UartMessage[3] == 'O' && UartMessage[4] == 'K') {
            InterfaceCmdStatus = INTERFACE_CMD_DONE;
        }
        //key message
        else if(UartMessage[1] == 'K' && UartMessage[2] == ' ') {
            InterfaceCmdStatus = INTERFACE_CMD_DONE; // @TODO see WTF is here
            KeypadData = UartMessage[3];
        }
        //error message
        else if(UartMessage[1] == 'E') { // @TODO error handling
            InterfaceCmdStatus = INTERFACE_CMD_DONE;
        }
        
//        ClearString(UartMessage, UART_MESSAGE_MAX_LENGTH + 1);
        UartMessage[0] = NULL_CHAR;
        UartMessageLength = 0;
    }
}
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

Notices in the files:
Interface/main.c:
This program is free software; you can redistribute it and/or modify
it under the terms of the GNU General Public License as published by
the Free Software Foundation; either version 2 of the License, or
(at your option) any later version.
